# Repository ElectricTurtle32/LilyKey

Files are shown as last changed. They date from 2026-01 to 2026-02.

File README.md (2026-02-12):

# LilyKey
An opensource split wireless keyboard
20260202_13h03m20s_grim
20260202_13h03m55s_grim

20260125_23h00m33s_grim

20260125_23h01m45s_grim

This keyboard uses low profile Choc V2 switchs, and a XIAO nRF52840 with ZMK. 
The design fits together with only a few screws on the bottom

Firmware can be found in this repo

OnShape link. In order to use the link, copy it into your browser, for some reason if you don't do that you get a 403 error.
https://cad.onshape.com/documents/438c57f3dff6ca4edb0a97ae/w/4621db7fe7b2abded9ecab59/e/34fd1f2b97a3de8af004570b

I will be buying the lubrication kit, and tribosys 3204 out of pocket, due to overbudget constraints. If required, I will also be buying the diodes and JST connectors out of pocket.\
BOM
| Description | Link | Qty. | Price Per Unit | Total Price |
| --- | --- | ---- | --- | --- |
| JST PH connector | [LINK](https://www.digikey.com/en/products/detail/jst-sales-america-inc/S2B-PH-SM4-TB/926655) | 4 | $0.48 | $1.92 |
| Diodes | [LINK](https://www.digikey.com/en/products/detail/smc-diode-solutions/1N4148W/6022450) | 100  | $0.05 | $4.74 |
| Switches | [LINK](https://chosfox.com/products/kailh-four-seasons-mini-low-profile-linear-switches?variant=45837283131586) | 70 | $0.48 | $33.60 |
| XIAO nRF52840 | [LINK](https://www.seeedstudio.com/Seeed-Studio-XIAO-nRF52840-3PCS-p-5921.html) | 2 | $9.90 | $19.80 |
| Battery | [LINK](https://www.digikey.com/en/products/detail/adafruit-industries-llc/1578/5054539) | 2 | $7.95 | $15.90 |
| Lube (3204) | [LINK](https://mech.land/products/tribosys-3204-lubricant-in-stock) | 1 | $6.00 | $6.00 |
| Lubing Kit | [LINK](https://chosfox.com/products/lubing-kit?variant=42670168473794) | 1 | $5.00 | $5.00 |
| Keycaps | [LINK](https://chosfox.com/products/chocfox-cfx-choc-keycaps?variant=42165428289730) | 7 | $3.50 | $24.50 |
| | | | | Total cost  |
| | | | | $111.46 |

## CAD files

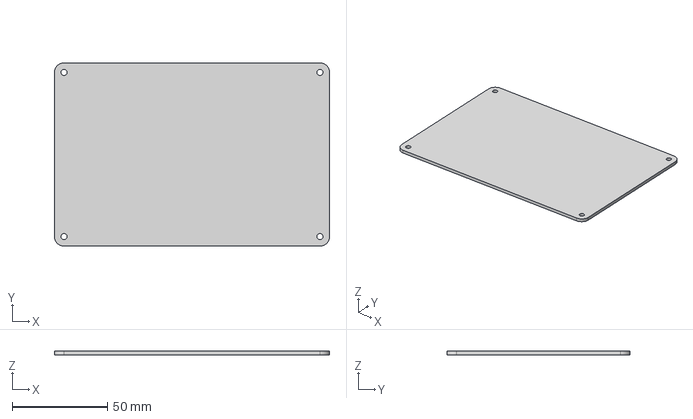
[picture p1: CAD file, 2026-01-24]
Case/Bottom Cover.step
144.0 x 96.0 x 2.00 mm

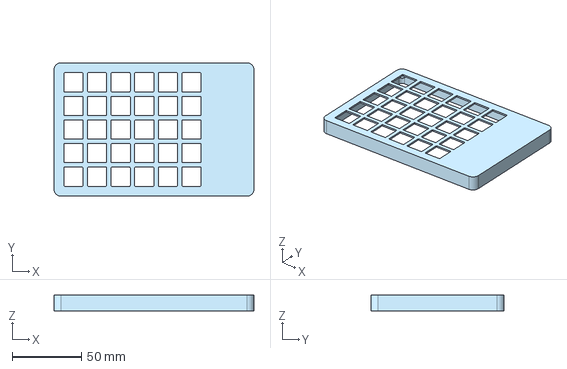
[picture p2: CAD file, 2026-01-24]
Case/Top Cover.step
144.0 x 96.0 x 11.2 mm

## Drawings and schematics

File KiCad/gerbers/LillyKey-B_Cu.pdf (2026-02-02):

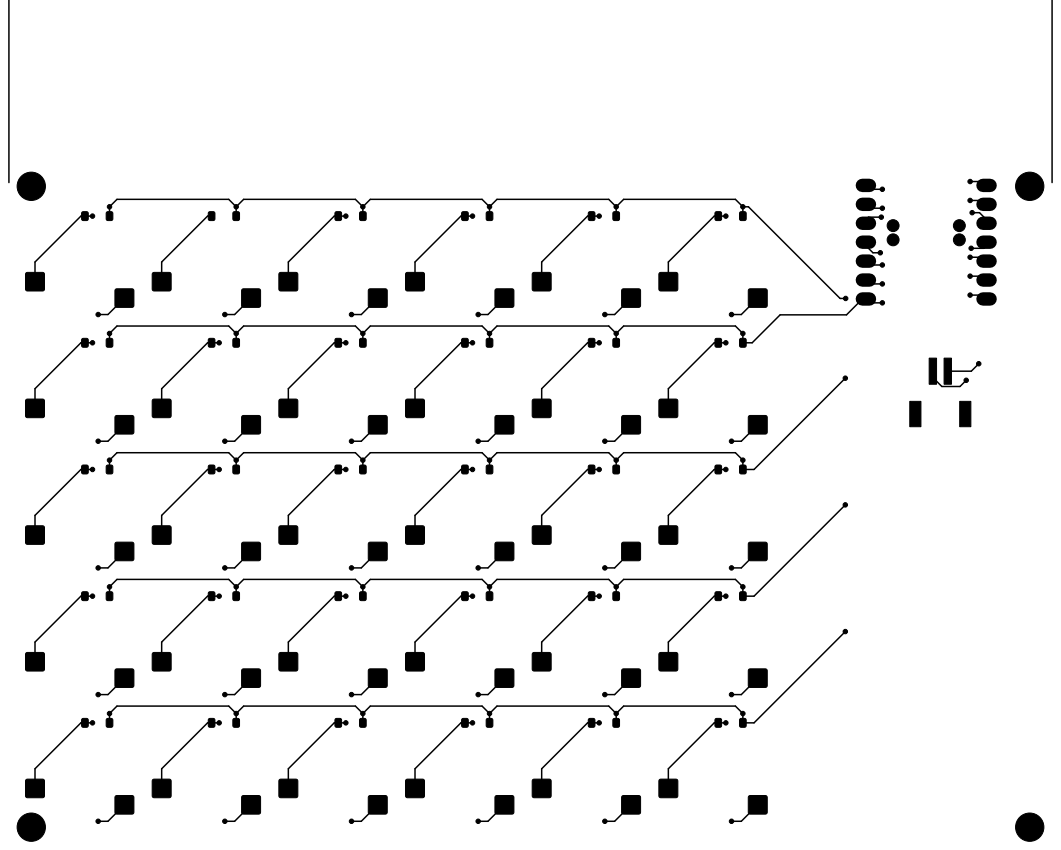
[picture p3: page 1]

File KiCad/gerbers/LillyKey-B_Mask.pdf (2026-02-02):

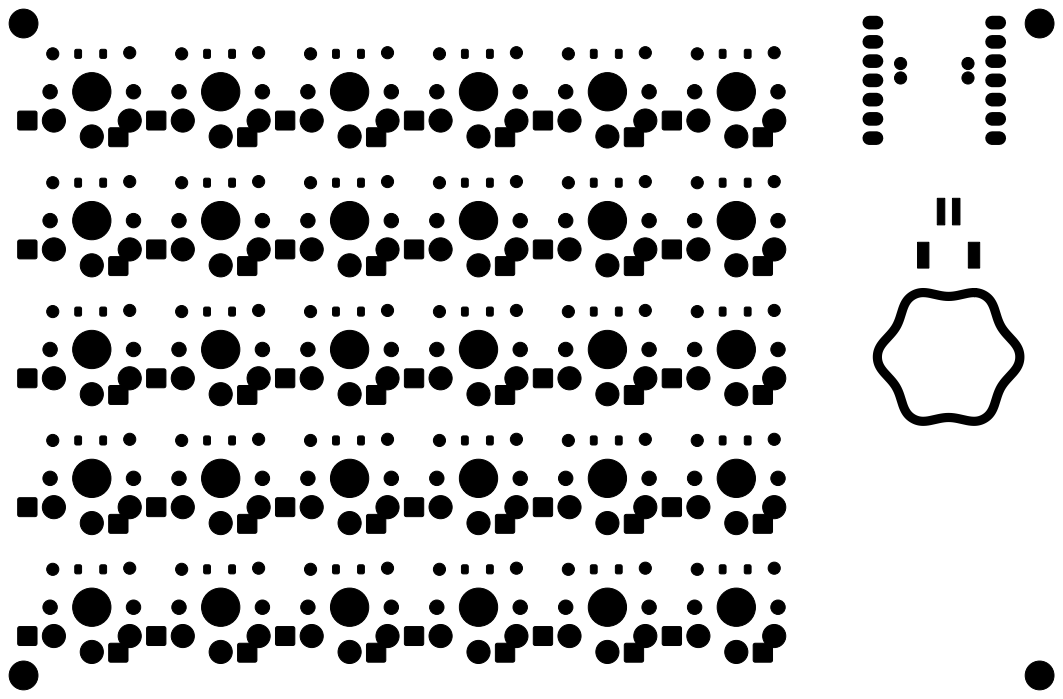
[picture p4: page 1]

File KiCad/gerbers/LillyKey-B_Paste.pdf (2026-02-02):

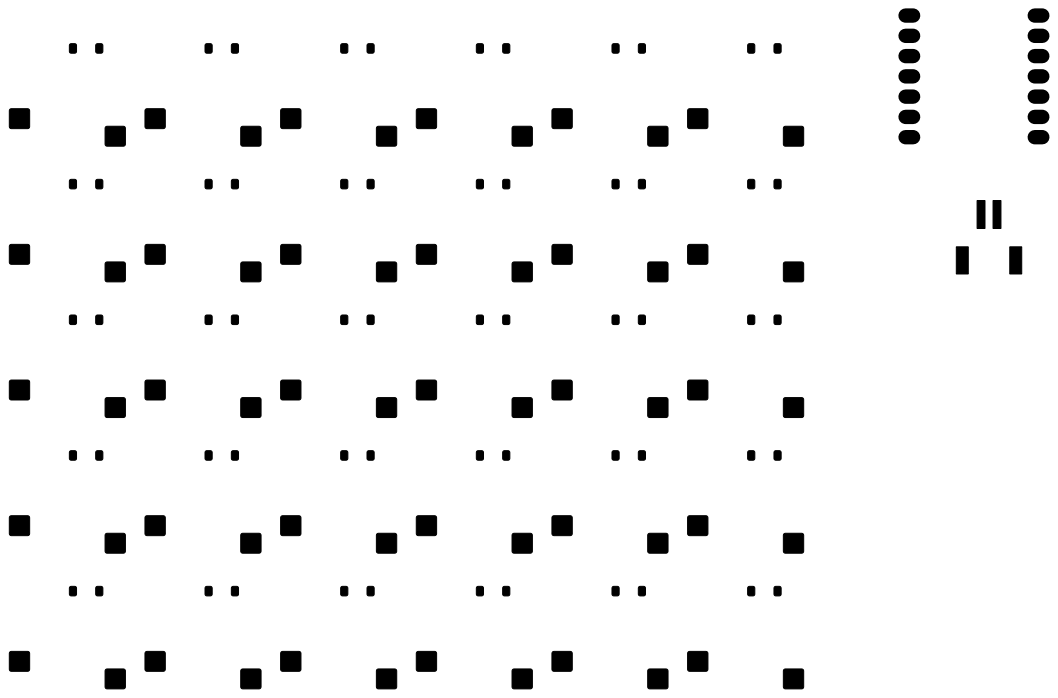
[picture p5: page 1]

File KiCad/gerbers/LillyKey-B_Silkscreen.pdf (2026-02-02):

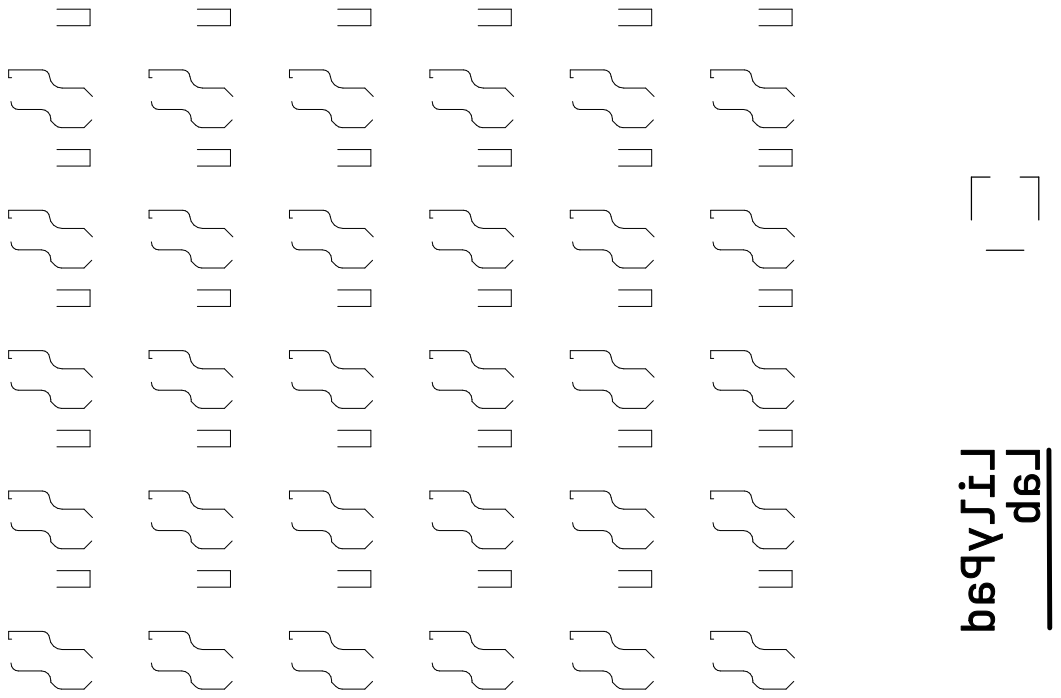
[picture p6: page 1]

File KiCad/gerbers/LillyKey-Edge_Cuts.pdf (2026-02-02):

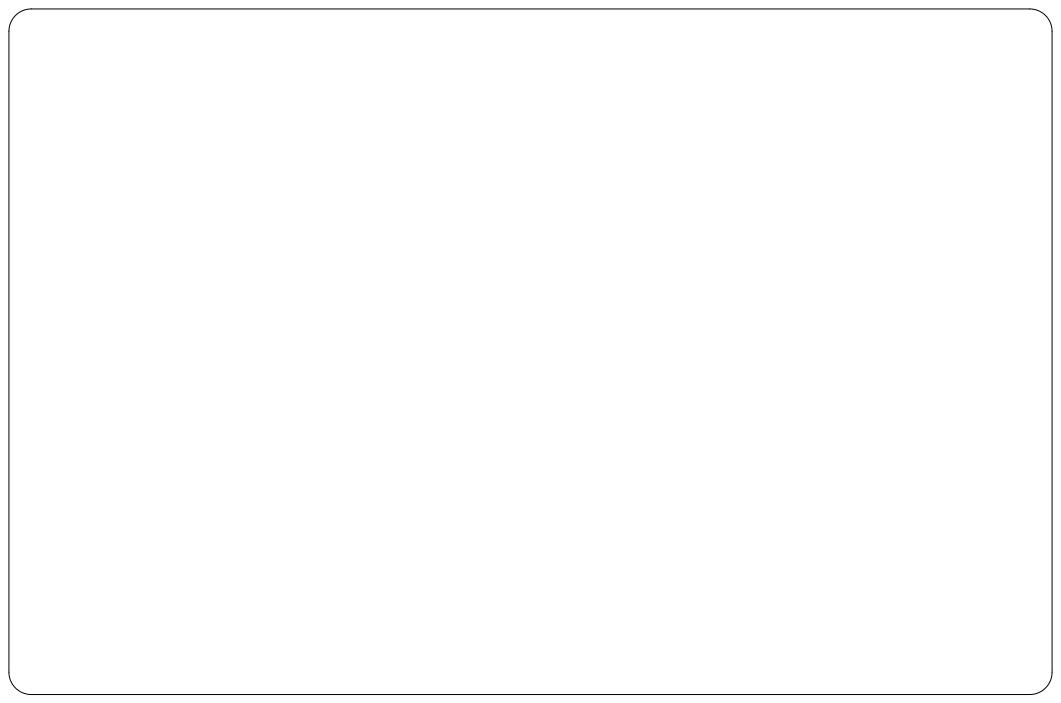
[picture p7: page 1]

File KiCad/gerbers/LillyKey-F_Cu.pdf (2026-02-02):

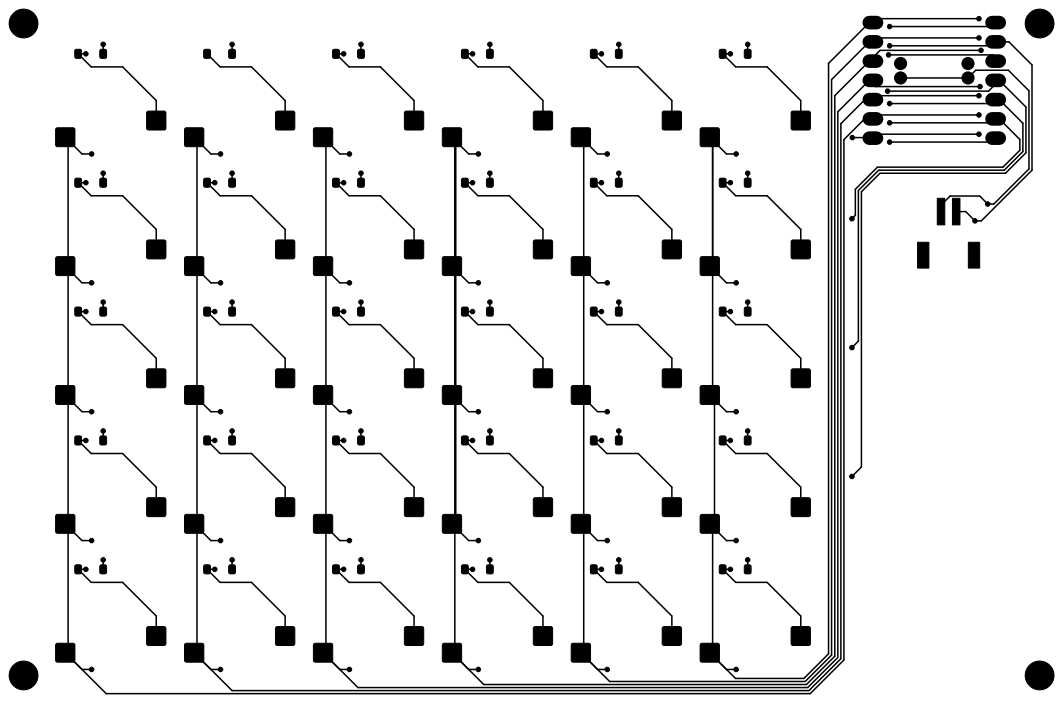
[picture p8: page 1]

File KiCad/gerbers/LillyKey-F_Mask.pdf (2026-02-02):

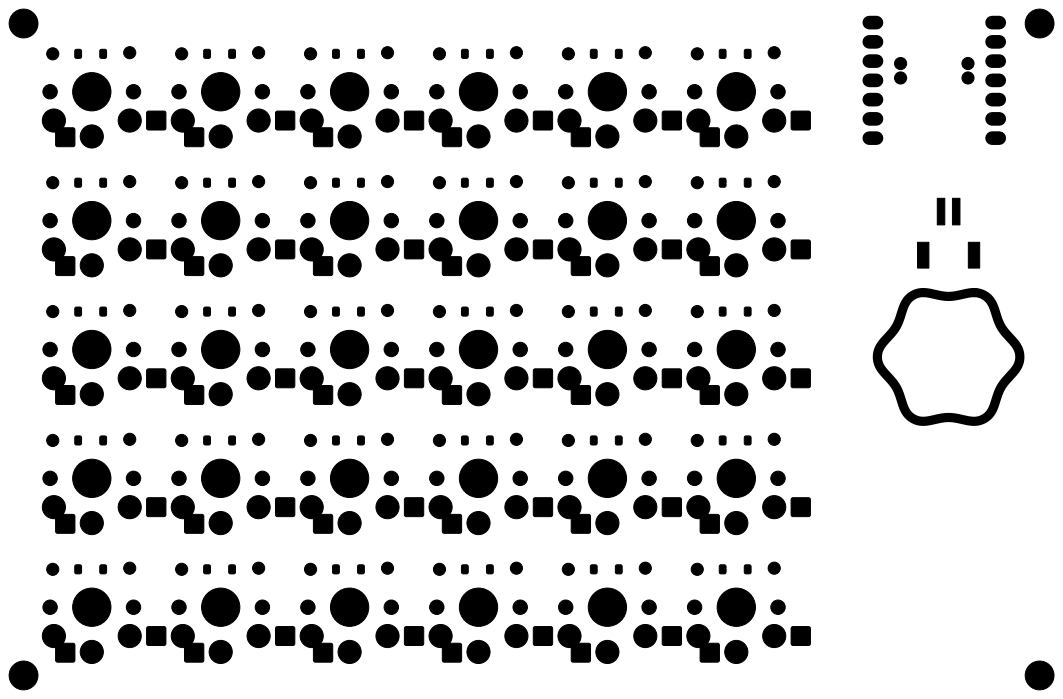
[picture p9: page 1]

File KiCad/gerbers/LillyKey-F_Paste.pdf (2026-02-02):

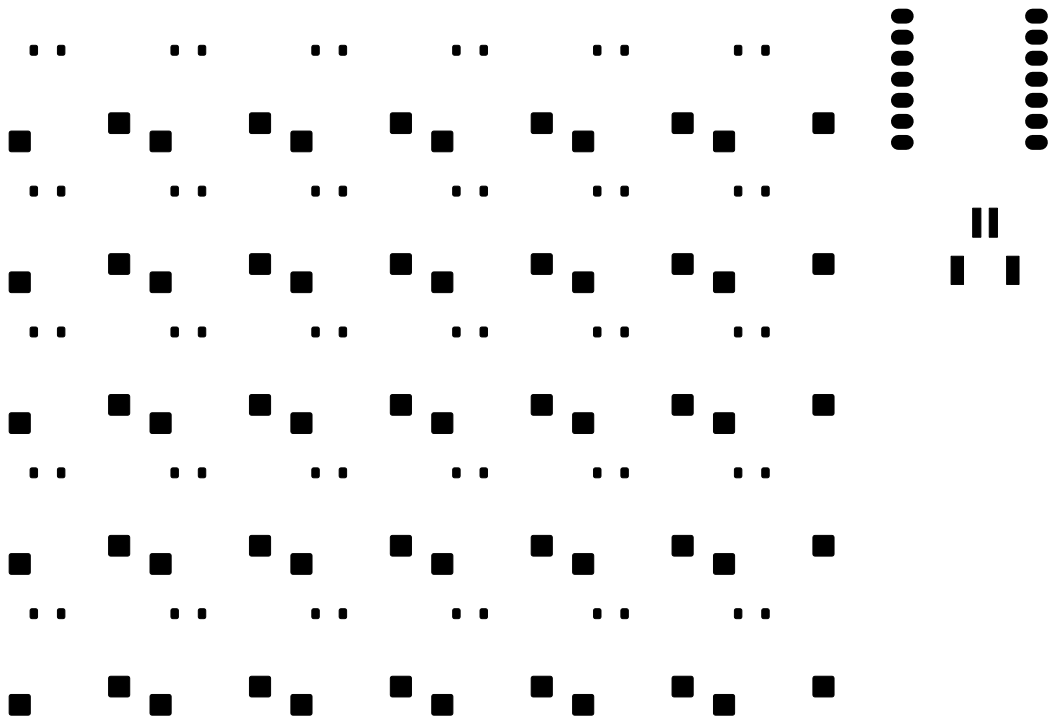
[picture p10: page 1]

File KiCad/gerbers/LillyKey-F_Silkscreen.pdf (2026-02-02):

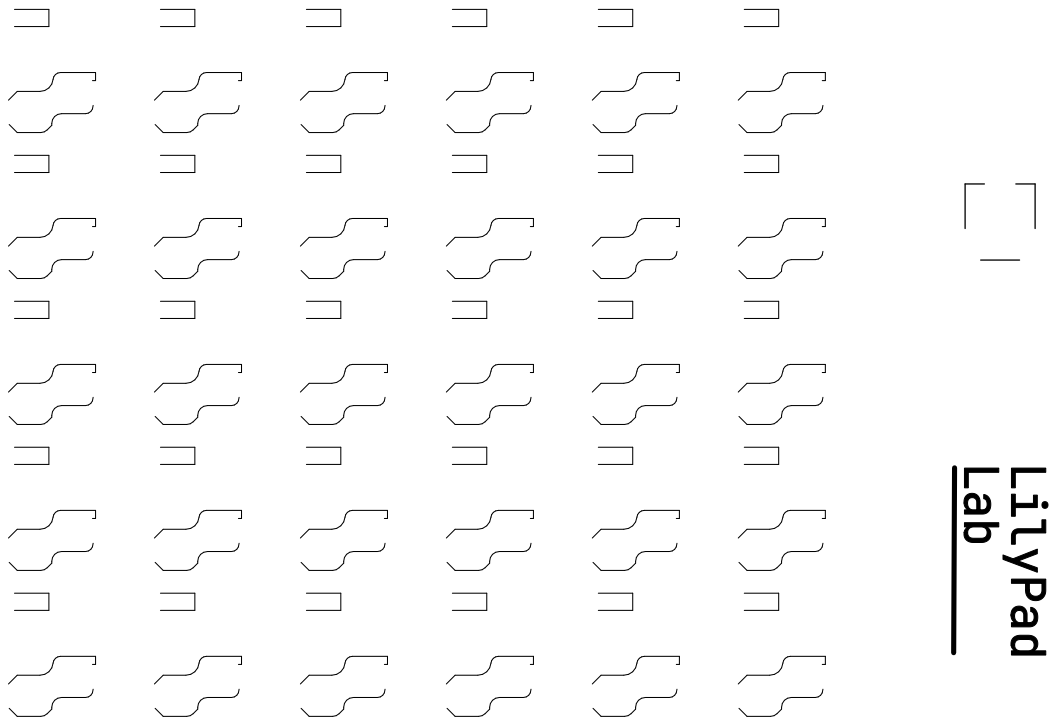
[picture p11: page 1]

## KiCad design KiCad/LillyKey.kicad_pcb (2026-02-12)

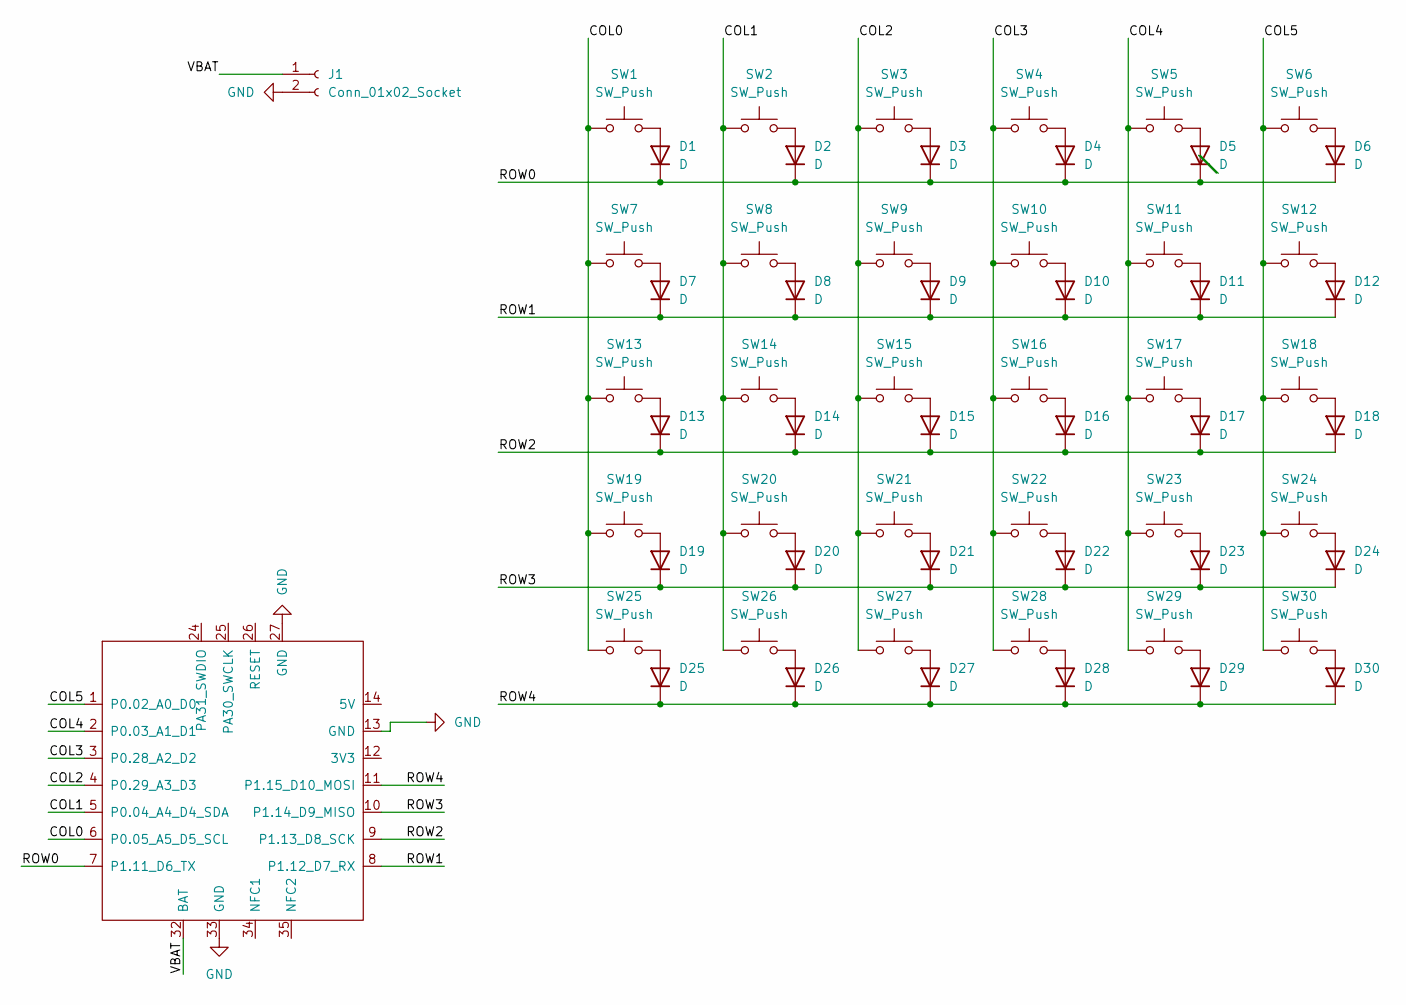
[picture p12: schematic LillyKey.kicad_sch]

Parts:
D1, D2, D3, D4, D5, D6, D7, D8, D9, D10, D11, D12, D13, D14, D15, D16, D17, D18, D19, D20, D21, D22, D23, D24, D25, D26, D27, D28, D29, D30: D; RevDiode
J1: Conn_01x02_Socket; JSTPH
SW1, SW2, SW3, SW4, SW5, SW6, SW7, SW8, SW9, SW10, SW11, SW12, SW13, SW14, SW15, SW16, SW17, SW18, SW19, SW20, SW21, SW22, SW23, SW24, SW25, SW26, SW27, SW28, SW29, SW30: SW_Push; SW_Hotswap_Kailh_Choc_V1V2
U2: XIAO-nRF52840-SMD; XIAO_nRF52840_DUAL

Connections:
/COL0: SW1.1, SW7.1, SW13.1, SW19.1, SW25.1, U2.6 (P0.05_A5_D5_SCL)
/COL1: SW2.1, SW8.1, SW14.1, SW20.1, SW26.1, U2.5 (P0.04_A4_D4_SDA)
/COL2: SW3.1, SW9.1, SW15.1, SW21.1, SW27.1, U2.4 (P0.29_A3_D3)
/COL3: SW4.1, SW10.1, SW16.1, SW22.1, SW28.1, U2.3 (P0.28_A2_D2)
/COL4: SW5.1, SW11.1, SW17.1, SW23.1, SW29.1, U2.2 (P0.03_A1_D1)
/COL5: SW6.1, SW12.1, SW18.1, SW24.1, SW30.1, U2.1 (P0.02_A0_D0)
/ROW0: D1.1 (K), D2.1 (K), D3.1 (K), D4.1 (K), D5.1 (K), D6.1 (K), U2.7 (P1.11_D6_TX)
/ROW1: D7.1 (K), D8.1 (K), D9.1 (K), D10.1 (K), D11.1 (K), D12.1 (K), U2.8 (P1.12_D7_RX)
/ROW2: D13.1 (K), D14.1 (K), D15.1 (K), D16.1 (K), D17.1 (K), D18.1 (K), U2.9 (P1.13_D8_SCK)
/ROW3: D19.1 (K), D20.1 (K), D21.1 (K), D22.1 (K), D23.1 (K), D24.1 (K), U2.10 (P1.14_D9_MISO)
/ROW4: D25.1 (K), D26.1 (K), D27.1 (K), D28.1 (K), D29.1 (K), D30.1 (K), U2.11 (P1.15_D10_MOSI)
/VBAT: J1.1, U2.32 (BAT)
GND: J1.2, U2.13 (GND), U2.27 (GND), U2.33 (GND)
unnamed: D1.2 (A), SW1.2
unnamed: D2.2 (A), SW2.2
unnamed: D3.2 (A), SW3.2
unnamed: D4.2 (A), SW4.2
unnamed: D5.2 (A), SW5.2
unnamed: D6.2 (A), SW6.2
unnamed: D7.2 (A), SW7.2
unnamed: D8.2 (A), SW8.2
unnamed: D9.2 (A), SW9.2
unnamed: D10.2 (A), SW10.2
unnamed: D11.2 (A), SW11.2
unnamed: D12.2 (A), SW12.2
unnamed: D13.2 (A), SW13.2
unnamed: D14.2 (A), SW14.2
unnamed: D15.2 (A), SW15.2
unnamed: D16.2 (A), SW16.2
unnamed: D17.2 (A), SW17.2
unnamed: D18.2 (A), SW18.2
unnamed: D19.2 (A), SW19.2
unnamed: D20.2 (A), SW20.2
unnamed: D21.2 (A), SW21.2
unnamed: D22.2 (A), SW22.2
unnamed: D23.2 (A), SW23.2
unnamed: D24.2 (A), SW24.2
unnamed: D25.2 (A), SW25.2
unnamed: D26.2 (A), SW26.2
unnamed: D27.2 (A), SW27.2
unnamed: D28.2 (A), SW28.2
unnamed: D29.2 (A), SW29.2
unnamed: D30.2 (A), SW30.2

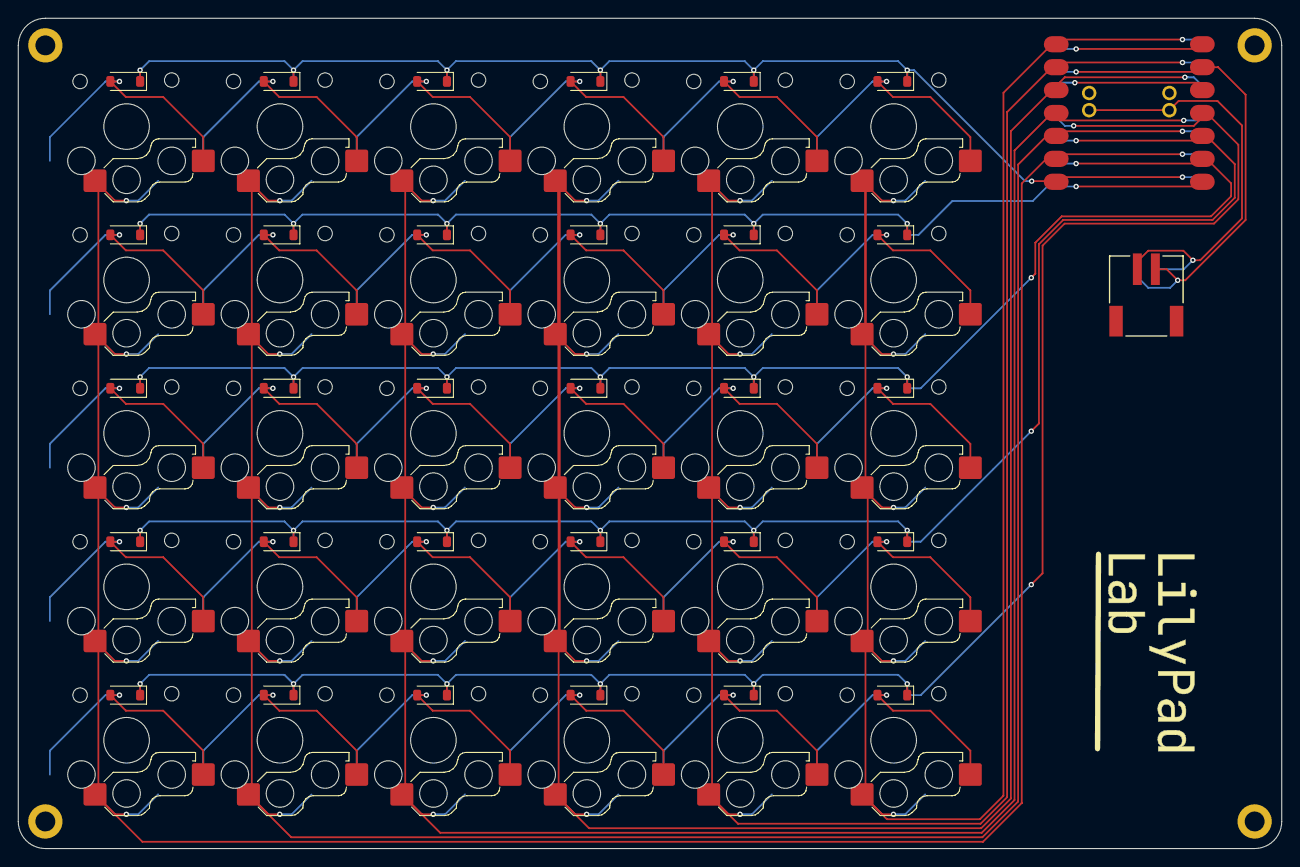
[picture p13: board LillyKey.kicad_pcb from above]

Board: 2 copper layers, 140.0 x 92.0 mm, 62 parts (1 on the bottom side), 42 nets.

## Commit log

2026-01-24 Add KiCad
    [LillyKey-B_Cu.gbr, LillyKey-B_Mask.gbr, LillyKey-B_Paste.gbr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]
2026-01-24 Add case files
    [Bottom Cover.step, Top Cover.step]
2026-01-24 Add BOM section with component details to README
    Added a Bill of Materials (BOM) section with links and pricing for components.
2026-01-24 Add extra image
    Added a BOM section with details and a link to a JST PH connector.
2026-01-26 Update README with new images and BOM details
    Added additional images and updated BOM section with new information.
2026-02-02 Fliped around keys, cleanup
    [LillyKey-B_Cu.gbr, LillyKey-B_Mask.gbr, LillyKey-B_Paste.gbr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]
2026-02-05 Change Battery
2026-02-12 Fix links in README for CAD files and firmware
    Updated links for CAD files and firmware repository in README.
2026-02-12 Update README with OnShape link and BOM information
    Added OnShape link and updated BOM details.
2026-02-12 Add OnShape link to README
    Added OnShape link for CAD documentation.
2026-02-12 Removed v1 holes
    [LillyKey.kicad_pcb]
